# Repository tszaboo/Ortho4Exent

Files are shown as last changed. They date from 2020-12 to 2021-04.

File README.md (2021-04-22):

# Ortho4Exent
Ortholinear keyboard for Exent case

Done in Altium Designer 21.2

Firmware: QMK
The keyboard is found in the QMK repository:\
https://github.com/qmk/qmk_firmware/tree/master/keyboards/tszaboo/ortho4exent

Or build it with the qmk configurator:\
https://config.qmk.fm/#/tszaboo/ortho4exent/LAYOUT

Layout\
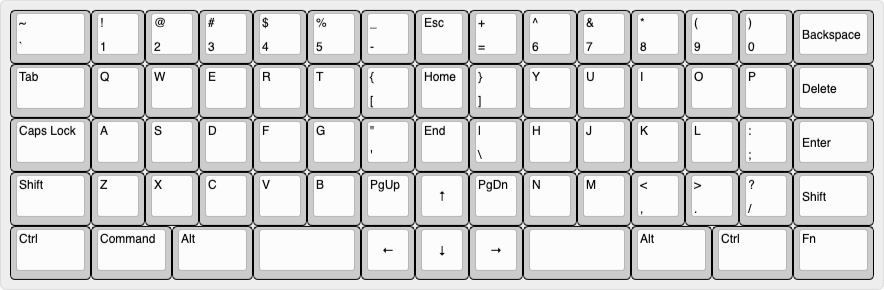
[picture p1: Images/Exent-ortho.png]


PCB\
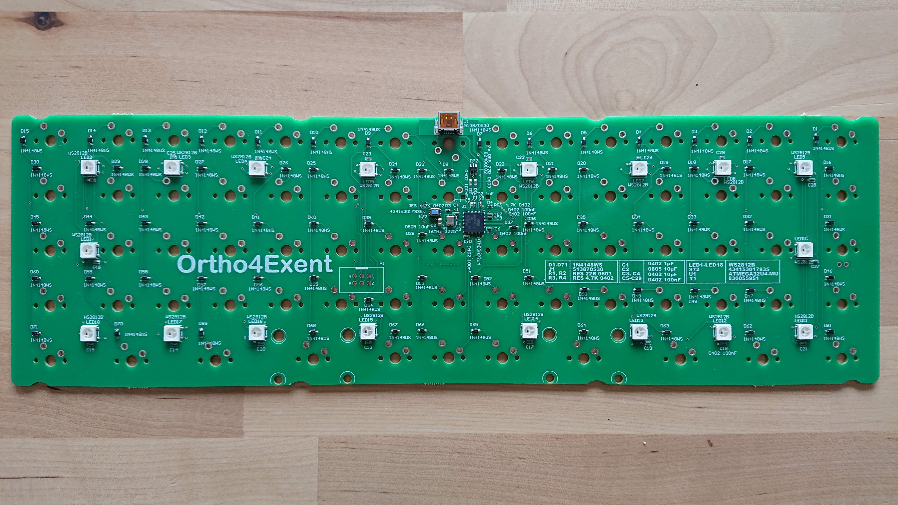
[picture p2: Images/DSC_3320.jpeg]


Assembled board\
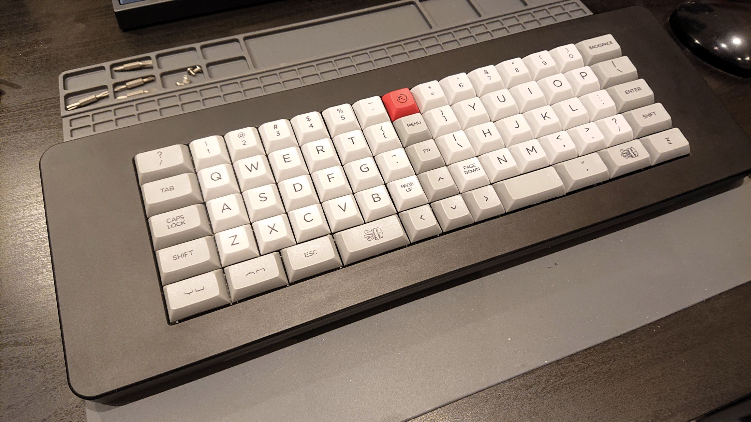
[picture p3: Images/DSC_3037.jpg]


tszaboo \
2021

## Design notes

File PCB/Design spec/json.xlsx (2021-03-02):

{"label":"k00", | x:0, | y:0}, |  | {"label":" | k | 0 | 0 | ","x": | 0 | ,"y": | 0 | ,"w":1.5 | }, | {"label":"k00","x":0,"y":0,"w":1.5},
{"label":"k01", | x:1, | y:0}, |  | {"label":" | k | 0 | 1 | ","x": | 1.5 | ,"y": | 0 |  | }, | {"label":"k01","x":1.5,"y":0},
{"label":"k02", | x:2, | y:0}, |  | {"label":" | k | 0 | 2 | ","x": | 2.5 | ,"y": | 0 |  | }, | {"label":"k02","x":2.5,"y":0},
{"label":"S4", | x:3, | y:0}, |  | {"label":" | k | 0 | 3 | ","x": | 3.5 | ,"y": | 0 |  | }, | {"label":"k03","x":3.5,"y":0},
{"label":"", | x:4, | y:0}, |  | {"label":" | k | 0 | 4 | ","x": | 4.5 | ,"y": | 0 |  | }, | {"label":"k04","x":4.5,"y":0},
{"label":"", | x:5, | y:0}, |  | {"label":" | k | 0 | 5 | ","x": | 5.5 | ,"y": | 0 |  | }, | {"label":"k05","x":5.5,"y":0},
{"label":"", | x:6, | y:0}, |  | {"label":" | k | 0 | 6 | ","x": | 6.5 | ,"y": | 0 |  | }, | {"label":"k06","x":6.5,"y":0},
{"label":"", | x:7, | y:0}, |  | {"label":" | k | 0 | 7 | ","x": | 7.5 | ,"y": | 0 |  | }, | {"label":"k07","x":7.5,"y":0},
{"label":"", | x:8, | y:0}, |  | {"label":" | k | 0 | 8 | ","x": | 8.5 | ,"y": | 0 |  | }, | {"label":"k08","x":8.5,"y":0},
{"label":"", | x:9, | y:0}, |  | {"label":" | k | 0 | 9 | ","x": | 9.5 | ,"y": | 0 |  | }, | {"label":"k09","x":9.5,"y":0},
{"label":"", | x:10, | y:0}, |  | {"label":" | k | 0 | A | ","x": | 10.5 | ,"y": | 0 |  | }, | {"label":"k0A","x":10.5,"y":0},
{"label":"", | x:11, | y:0}, |  | {"label":" | k | 0 | B | ","x": | 11.5 | ,"y": | 0 |  | }, | {"label":"k0B","x":11.5,"y":0},
{"label":"", | x:12, | y:0}, |  | {"label":" | k | 0 | C | ","x": | 12.5 | ,"y": | 0 |  | }, | {"label":"k0C","x":12.5,"y":0},
{"label":"", | x:13, | y:0}, |  | {"label":" | k | 0 | D | ","x": | 13.5 | ,"y": | 0 |  | }, | {"label":"k0D","x":13.5,"y":0},
{"label":"", | x:14, | y:0}, |  | {"label":" | k | 0 | E | ","x": | 14.5 | ,"y": | 0 | ,"w":1.5 | }, | {"label":"k0E","x":14.5,"y":0,"w":1.5},
{"label":"", | x:15, | y:0}, |  | {"label":" | k | 1 | 0 | ","x": | 0 | ,"y": | 1 | ,"w":1.5 | }, | {"label":"k10","x":0,"y":1,"w":1.5},
{"label":"", | x:0, | y:1, | w:1.5}, | {"label":" | k | 1 | 1 | ","x": | 1.5 | ,"y": | 1 |  | }, | {"label":"k11","x":1.5,"y":1},
{"label":"", | x:1.5, | y:1}, |  | {"label":" | k | 1 | 2 | ","x": | 2.5 | ,"y": | 1 |  | }, | {"label":"k12","x":2.5,"y":1},
{"label":"", | x:2.5, | y:1}, |  | {"label":" | k | 1 | 3 | ","x": | 3.5 | ,"y": | 1 |  | }, | {"label":"k13","x":3.5,"y":1},
{"label":"", | x:3.5, | y:1}, |  | {"label":" | k | 1 | 4 | ","x": | 4.5 | ,"y": | 1 |  | }, | {"label":"k14","x":4.5,"y":1},
{"label":"", | x:4.5, | y:1}, |  | {"label":" | k | 1 | 5 | ","x": | 5.5 | ,"y": | 1 |  | }, | {"label":"k15","x":5.5,"y":1},
{"label":"", | x:5.5, | y:1}, |  | {"label":" | k | 1 | 6 | ","x": | 6.5 | ,"y": | 1 |  | }, | {"label":"k16","x":6.5,"y":1},
{"label":"", | x:6.5, | y:1}, |  | {"label":" | k | 1 | 7 | ","x": | 7.5 | ,"y": | 1 |  | }, | {"label":"k17","x":7.5,"y":1},
{"label":"", | x:7.5, | y:1}, |  | {"label":" | k | 1 | 8 | ","x": | 8.5 | ,"y": | 1 |  | }, | {"label":"k18","x":8.5,"y":1},
{"label":"", | x:8.5, | y:1}, |  | {"label":" | k | 1 | 9 | ","x": | 9.5 | ,"y": | 1 |  | }, | {"label":"k19","x":9.5,"y":1},
{"label":"", | x:9.5, | y:1}, |  | {"label":" | k | 1 | A | ","x": | 10.5 | ,"y": | 1 |  | }, | {"label":"k1A","x":10.5,"y":1},
{"label":"", | x:10.5, | y:1}, |  | {"label":" | k | 1 | B | ","x": | 11.5 | ,"y": | 1 |  | }, | {"label":"k1B","x":11.5,"y":1},
{"label":"", | x:11.5, | y:1}, |  | {"label":" | k | 1 | C | ","x": | 12.5 | ,"y": | 1 |  | }, | {"label":"k1C","x":12.5,"y":1},
{"label":"", | x:12.5, | y:1}, |  | {"label":" | k | 1 | D | ","x": | 13.5 | ,"y": | 1 |  | }, | {"label":"k1D","x":13.5,"y":1},
{"label":"", | x:13.5, | y:1, | w:1.5}, | {"label":" | k | 1 | E | ","x": | 14.5 | ,"y": | 1 | ,"w":1.5 | }, | {"label":"k1E","x":14.5,"y":1,"w":1.5},
{"label":"", | x:15, | y:1}, |  | {"label":" | k | 2 | 0 | ","x": | 0 | ,"y": | 2 |  | }, | {"label":"k20","x":0,"y":2},
{"label":"", | x:0, | y:2, | w:1.75}, | {"label":" | k | 2 | 1 | ","x": | 1.5 | ,"y": | 2 |  | }, | {"label":"k21","x":1.5,"y":2},
{"label":"", | x:1.75, | y:2}, |  | {"label":" | k | 2 | 2 | ","x": | 2.5 | ,"y": | 2 |  | }, | {"label":"k22","x":2.5,"y":2},
{"label":"", | x:2.75, | y:2}, |  | {"label":" | k | 2 | 3 | ","x": | 3.5 | ,"y": | 2 |  | }, | {"label":"k23","x":3.5,"y":2},
{"label":"", | x:3.75, | y:2}, |  | {"label":" | k | 2 | 4 | ","x": | 4.5 | ,"y": | 2 |  | }, | {"label":"k24","x":4.5,"y":2},
{"label":"", | x:4.75, | y:2}, |  | {"label":" | k | 2 | 5 | ","x": | 5.5 | ,"y": | 2 |  | }, | {"label":"k25","x":5.5,"y":2},
{"label":"", | x:5.75, | y:2}, |  | {"label":" | k | 2 | 6 | ","x": | 6.5 | ,"y": | 2 |  | }, | {"label":"k26","x":6.5,"y":2},
{"label":"", | x:6.75, | y:2}, |  | {"label":" | k | 2 | 7 | ","x": | 7.5 | ,"y": | 2 |  | }, | {"label":"k27","x":7.5,"y":2},
{"label":"", | x:7.75, | y:2}, |  | {"label":" | k | 2 | 8 | ","x": | 8.5 | ,"y": | 2 |  | }, | {"label":"k28","x":8.5,"y":2},
{"label":"", | x:8.75, | y:2}, |  | {"label":" | k | 2 | 9 | ","x": | 9.5 | ,"y": | 2 |  | }, | {"label":"k29","x":9.5,"y":2},
{"label":"", | x:9.75, | y:2}, |  | {"label":" | k | 2 | A | ","x": | 10.5 | ,"y": | 2 |  | }, | {"label":"k2A","x":10.5,"y":2},
{"label":"", | x:10.75, | y:2}, |  | {"label":" | k | 2 | B | ","x": | 11.5 | ,"y": | 2 |  | }, | {"label":"k2B","x":11.5,"y":2},
{"label":"", | x:11.75, | y:2}, |  | {"label":" | k | 2 | C | ","x": | 12.5 | ,"y": | 2 |  | }, | {"label":"k2C","x":12.5,"y":2},
{"label":"", | x:12.75, | y:2, | w:2.25}, | {"label":" | k | 2 | D | ","x": | 13.5 | ,"y": | 2 |  | }, | {"label":"k2D","x":13.5,"y":2},
{"label":"", | x:15, | y:2}, |  | {"label":" | k | 2 | E | ","x": | 14.5 | ,"y": | 2 |  | }, | {"label":"k2E","x":14.5,"y":2},
{"label":"", | x:0, | y:3, | w:2.25}, | {"label":" | k | 3 | 0 | ","x": | 0 | ,"y": | 3 | ,"w":1.5 | }, | {"label":"k30","x":0,"y":3,"w":1.5},
{"label":"", | x:2.25, | y:3}, |  | {"label":" | k | 3 | 1 | ","x": | 1.5 | ,"y": | 3 |  | }, | {"label":"k31","x":1.5,"y":3},
{"label":"", | x:3.25, | y:3}, |  | {"label":" | k | 3 | 2 | ","x": | 2.5 | ,"y": | 3 |  | }, | {"label":"k32","x":2.5,"y":3},
{"label":"", | x:4.25, | y:3}, |  | {"label":" | k | 3 | 3 | ","x": | 3.5 | ,"y": | 3 |  | }, | {"label":"k33","x":3.5,"y":3},
{"label":"", | x:5.25, | y:3}, |  | {"label":" | k | 3 | 4 | ","x": | 4.5 | ,"y": | 3 |  | }, | {"label":"k34","x":4.5,"y":3},
{"label":"", | x:6.25, | y:3}, |  | {"label":" | k | 3 | 5 | ","x": | 5.5 | ,"y": | 3 |  | }, | {"label":"k35","x":5.5,"y":3},
{"label":"", | x:7.25, | y:3}, |  | {"label":" | k | 3 | 6 | ","x": | 6.5 | ,"y": | 3 |  | }, | {"label":"k36","x":6.5,"y":3},
{"label":"", | x:8.25, | y:3}, |  | {"label":" | k | 3 | 7 | ","x": | 7.5 | ,"y": | 3 |  | }, | {"label":"k37","x":7.5,"y":3},
{"label":"", | x:9.25, | y:3}, |  | {"label":" | k | 3 | 8 | ","x": | 8.5 | ,"y": | 3 |  | }, | {"label":"k38","x":8.5,"y":3},
{"label":"", | x:10.25, | y:3}, |  | {"label":" | k | 3 | 9 | ","x": | 9.5 | ,"y": | 3 |  | }, | {"label":"k39","x":9.5,"y":3},
{"label":"", | x:11.25, | y:3}, |  | {"label":" | k | 3 | A | ","x": | 10.5 | ,"y": | 3 |  | }, | {"label":"k3A","x":10.5,"y":3},
{"label":"", | x:12.25, | y:3, | w:1.75}, | {"label":" | k | 3 | B | ","x": | 11.5 | ,"y": | 3 |  | }, | {"label":"k3B","x":11.5,"y":3},
{"label":"", | x:14, | y:3}, |  | {"label":" | k | 3 | C | ","x": | 12.5 | ,"y": | 3 |  | }, | {"label":"k3C","x":12.5,"y":3},
{"label":"", | x:15, | y:3}, |  | {"label":" | k | 3 | D | ","x": | 13.5 | ,"y": | 3 |  | }, | {"label":"k3D","x":13.5,"y":3},
{"label":"", | x:0, | y:4, | w:1.5}, | {"label":" | k | 3 | E | ","x": | 14.5 | ,"y": | 3 | ,"w":1.5 | }, | {"label":"k3E","x":14.5,"y":3,"w":1.5},
{"label":"", | x:1.5, | y:4}, |  | {"label":" | k | 4 | 0 | ","x": | 0 | ,"y": | 4 | ,"w":1.5 | }, | {"label":"k40","x":0,"y":4,"w":1.5},
{"label":"", | x:2.5, | y:4, | w:1.5}, | {"label":" | k | 4 | 1 | ","x": | 1.5 | ,"y": | 4 | ,"w":1.5 | }, | {"label":"k41","x":1.5,"y":4,"w":1.5},
{"label":"", | x:4, | y:4, | w:7}, | {"label":" | k | 4 | 2 | ","x": | 3 | ,"y": | 4 | ,"w":1.5 | }, | {"label":"k42","x":3,"y":4,"w":1.5},
{"label":"", | x:11, | y:4, | w:1.5}, | {"label":" | k | 4 | 3 | ","x": | 4.5 | ,"y": | 4 | ,"w":2 | }, | {"label":"k43","x":4.5,"y":4,"w":2},
{"label":"", | x:13, | y:4}, |  | {"label":" | k | 4 | 4 | ","x": | 6.5 | ,"y": | 4 |  | }, | {"label":"k44","x":6.5,"y":4},
{"label":"", | x:14, | y:4}, |  | {"label":" | k | 4 | 5 | ","x": | 7.5 | ,"y": | 4 |  | }, | {"label":"k45","x":7.5,"y":4},
{"label":"", | x:15, | y:4} |  | {"label":" | k | 4 | 6 | ","x": | 8.5 | ,"y": | 4 |  | }, | {"label":"k46","x":8.5,"y":4},
 |  |  |  | {"label":" | k | 4 | 7 | ","x": | 9.5 | ,"y": | 4 | ,"w":2 | }, | {"label":"k47","x":9.5,"y":4,"w":2},
 |  |  |  | {"label":" | k | 4 | 8 | ","x": | 11.5 | ,"y": | 4 | ,"w":1.5 | }, | {"label":"k48","x":11.5,"y":4,"w":1.5},
 |  |  |  | {"label":" | k | 4 | 9 | ","x": | 13 | ,"y": | 4 | ,"w":1.5 | }, | {"label":"k49","x":13,"y":4,"w":1.5},
 |  |  |  | {"label":" | k | 4 | A | ","x": | 14.5 | ,"y": | 4 | ,"w":1.5 | }, | {"label":"k4A","x":14.5,"y":4,"w":1.5},

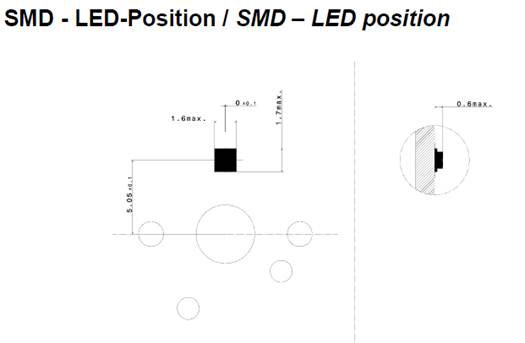
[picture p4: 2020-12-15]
PCB/Design spec/uCZFxpV.jpg

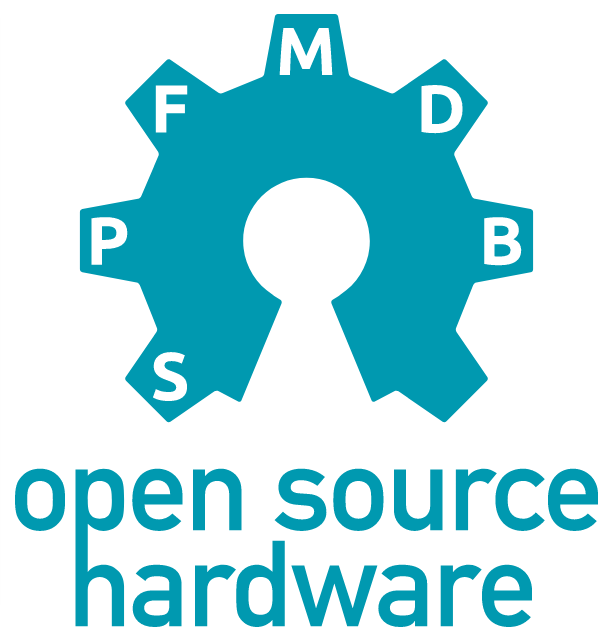
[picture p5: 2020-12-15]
PCB/Design spec/OSHW.PNG

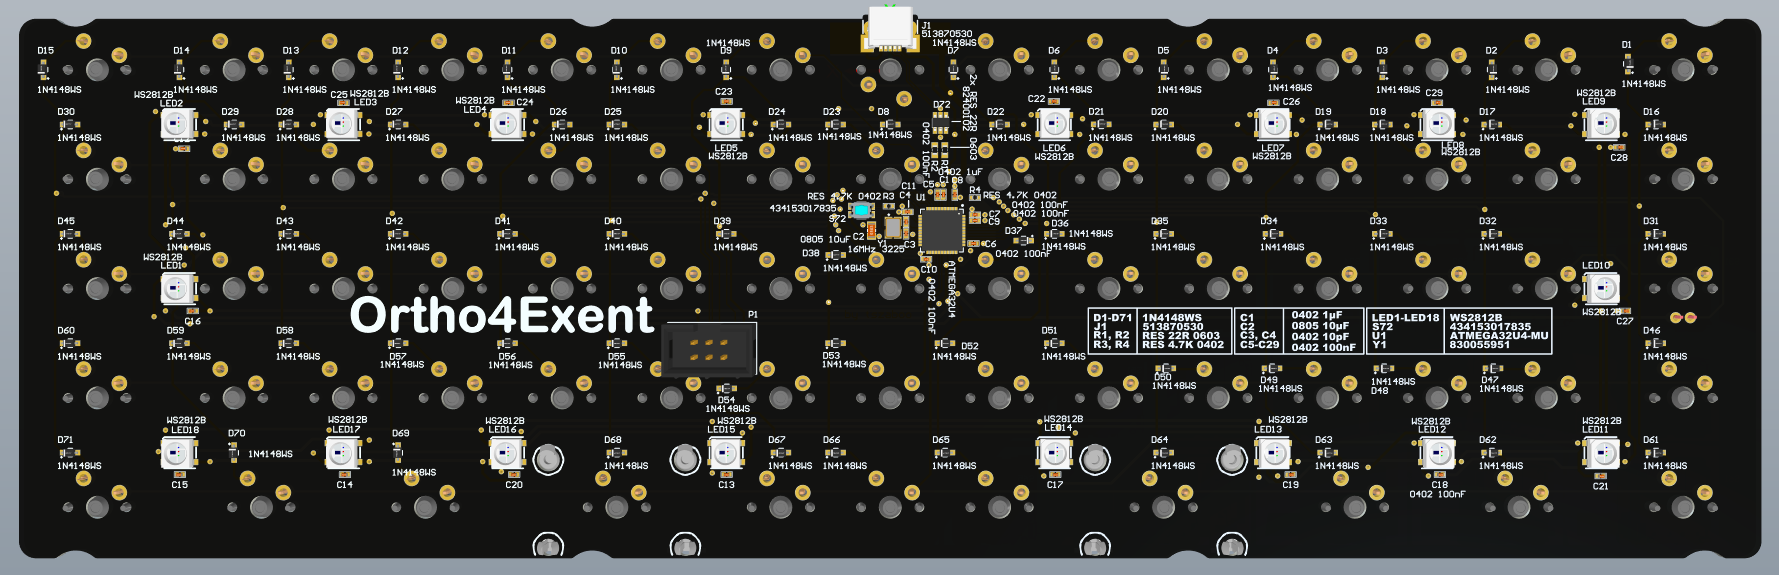
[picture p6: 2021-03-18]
Images/PCB Altium.PNG

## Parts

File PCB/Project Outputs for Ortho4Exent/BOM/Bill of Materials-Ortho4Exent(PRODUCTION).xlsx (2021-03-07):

Designator | Quantity | DESCIPTION | Footprint | MANUF | MANUFCODE
C1 | 1 | CAP SMD 0402 1 µF 10V X5R | CAPC0402N | WE | 885012105012
C2 | 1 | CAP SMD 0805 10 µF 10 V X5R | CAPC0805N | WE | 885012107010
C3, C4 | 2 | CAP SMD 0402 10 pF 10V NP0 | CAPC0402N | WE | 885012005007
C5, C6, C7, C8, C9, C10, C11, C12, C13, C14, C15, C16, C17, C18, C19, C20, C21, C22, C23, C24, C25, C26, C27, C28, C29 | 25 | CAP SMD 0402 100 nF 10V X5R | CAPC0402N | WE | 885012105010
D1, D2, D3, D4, D5, D6, D7, D8, D9, D10, D11, D12, D13, D14, D15, D16, D17, D18, D19, D20, D21, D22, D23, D24, D25, D26, D27, D28, D29, D30, D31, D32, D33, D34, D35, D36, D37, D38, D39, D40, D41, D42, D43, D44, D45, D46, D47, D48, D49, D50, D51, D52, D53, D54, D55, D56, D57, D58, D59, D60, D61, D62, D63, D64, D65, D66, D67, D68, D69, D70, D71 | 71 | DIODE GEN PURP 80V 125MA SOD323 | SOD323FL | ON Semi | 1N4148WS
D72 | 1 | WE-TVS TVS Diode, High Speed Series, SOT23-6L, VDC = 5V | SOT23-6L | WE | 82400102
J1 | 1 | USB - mini B USB 2.0 OTG Receptacle Connector 5 Position Surface Mount | 513870530 | MOLEX | 513870530
LED1, LED2, LED3, LED4, LED5, LED6, LED7, LED8, LED9, LED10, LED11, LED12, LED13, LED14, LED15, LED16, LED17, LED18 | 18 | ADDRESS LED RED/GRN/BLUE | WS2812 | Worldsemi | WS2812B
R1, R2 | 2 | RES SMD 22 OHM 1% 1/10W 100PPM 0603 | RESC0603N | VISHAY | CRCW060322R0FKEA
R3, R4 | 2 | RES SMD 4.7K OHM 1% 1/16W 100PPM 0402 | RESC0402N | VISHAY | CRCW04024K70FKED
S72 | 1 | SWITCH TACTILE SPST-NO 0.05A 12V | 434153017835 | WE | 434153017835
U1 | 1 | IC MCU 8BIT 32KB FLASH 44VQFN | 44PW_M | Microchip | ATMEGA32U4-MU-ND
Y1 | 1 | CRYSTAL 16.0000MHZ 18PF SMD | WE-XTAL_CFPX-180 | WE/IQD | 830055951

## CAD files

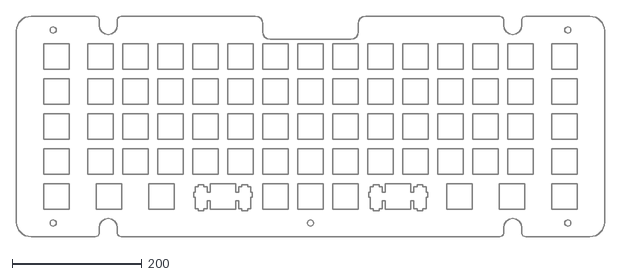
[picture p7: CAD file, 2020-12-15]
PCB/Design spec/ortho_plate.dxf
906.9 x 340.1

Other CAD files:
PCB/Design spec/PCB_layout.dwg
PCB/Plate/AutoCAD PCB/pcb.DWG
PCB/Design spec/65-PLATE-01_dimension.dwg

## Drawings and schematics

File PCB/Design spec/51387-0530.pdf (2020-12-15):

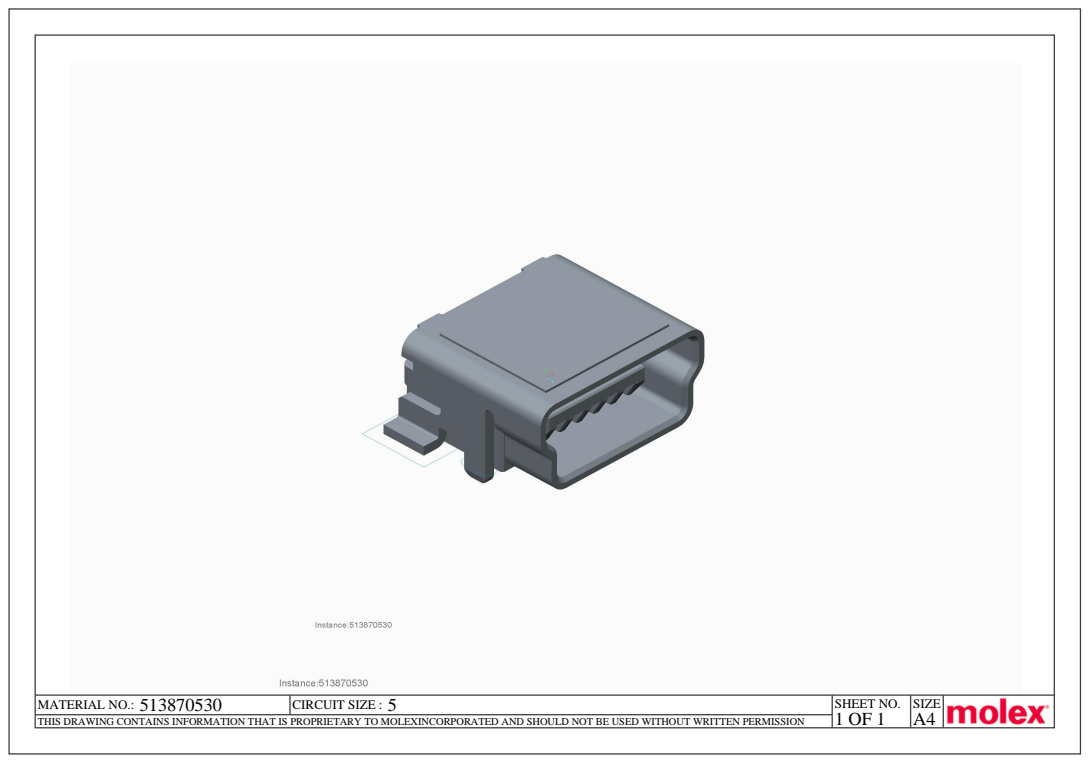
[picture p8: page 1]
MATERIAL NO.: 513870530; CIRCUIT SIZE : 5; SHEET NO.; SIZE

THIS DRAWING CONTAINS INFORMATION THAT IS PROPRIETARY TO MOLEXINCORPORATED AND SHOULD NOT BE USED WITHOUT WRITTEN PERMISSION

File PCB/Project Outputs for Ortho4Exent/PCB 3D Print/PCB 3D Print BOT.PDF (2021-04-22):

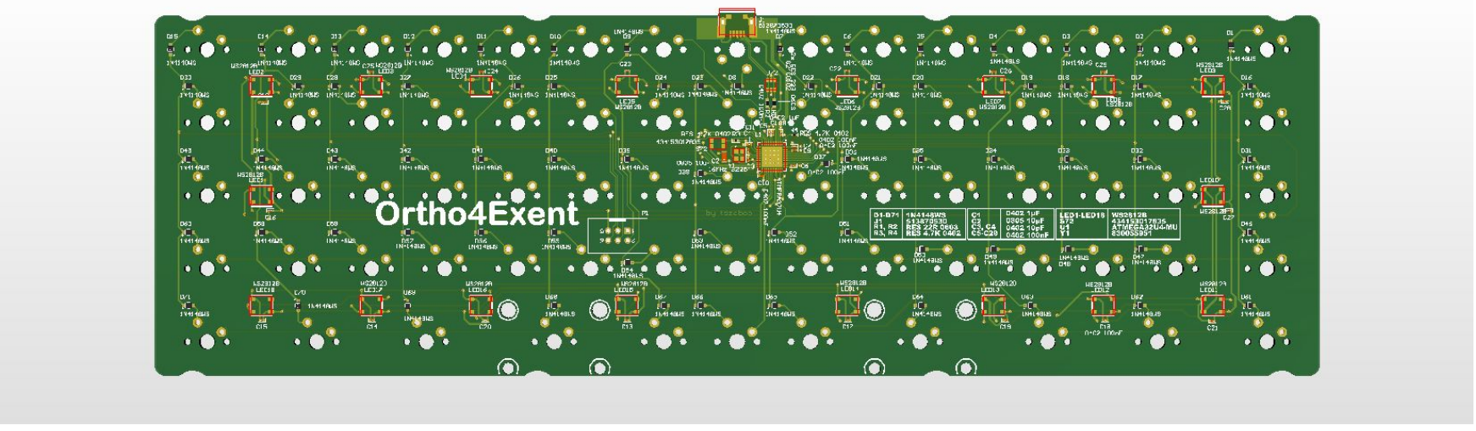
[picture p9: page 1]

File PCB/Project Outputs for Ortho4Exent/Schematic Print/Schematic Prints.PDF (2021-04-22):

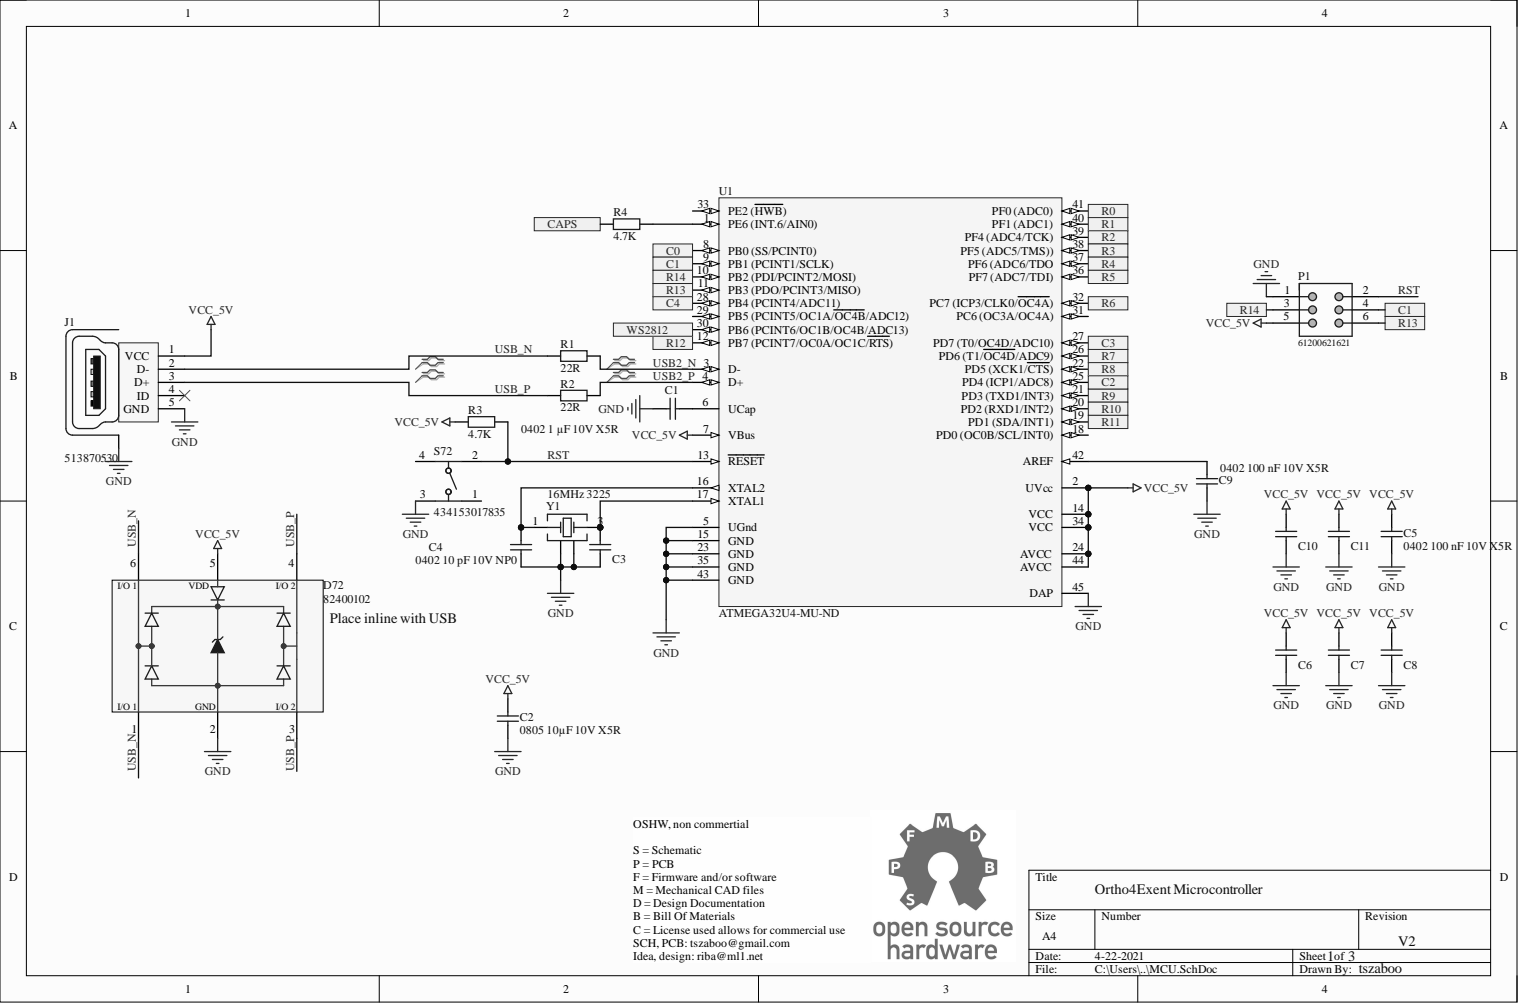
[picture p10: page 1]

C1 | | | R4
R1 4 | | | R5

1 6MHz 3 2 2 5 | 1 7 | 1 4

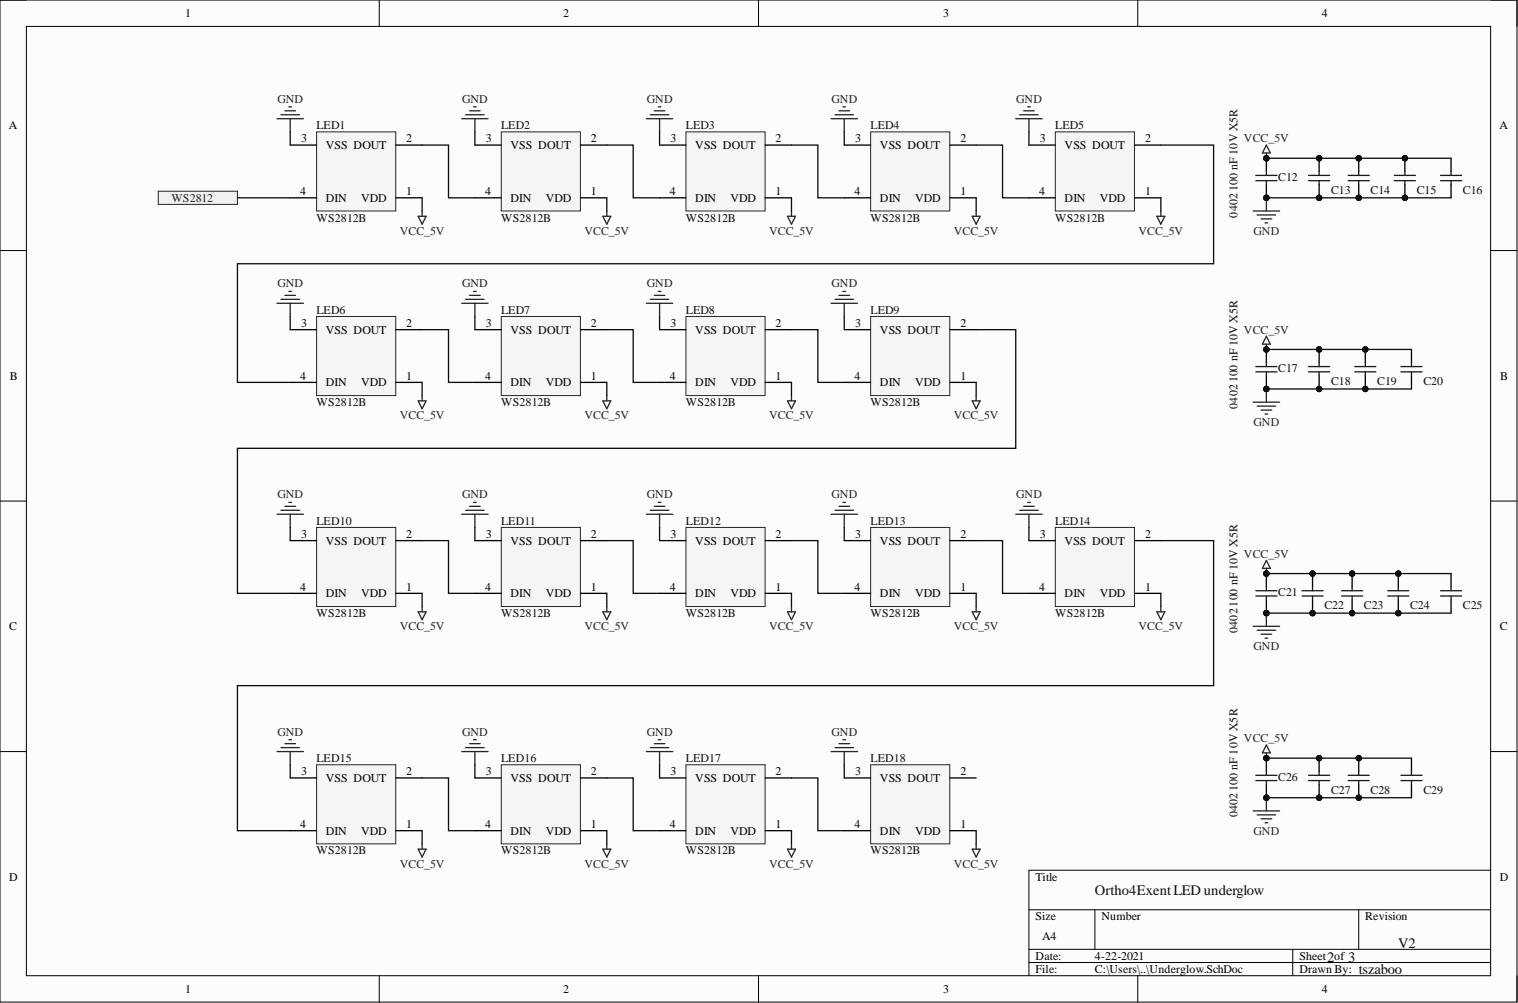
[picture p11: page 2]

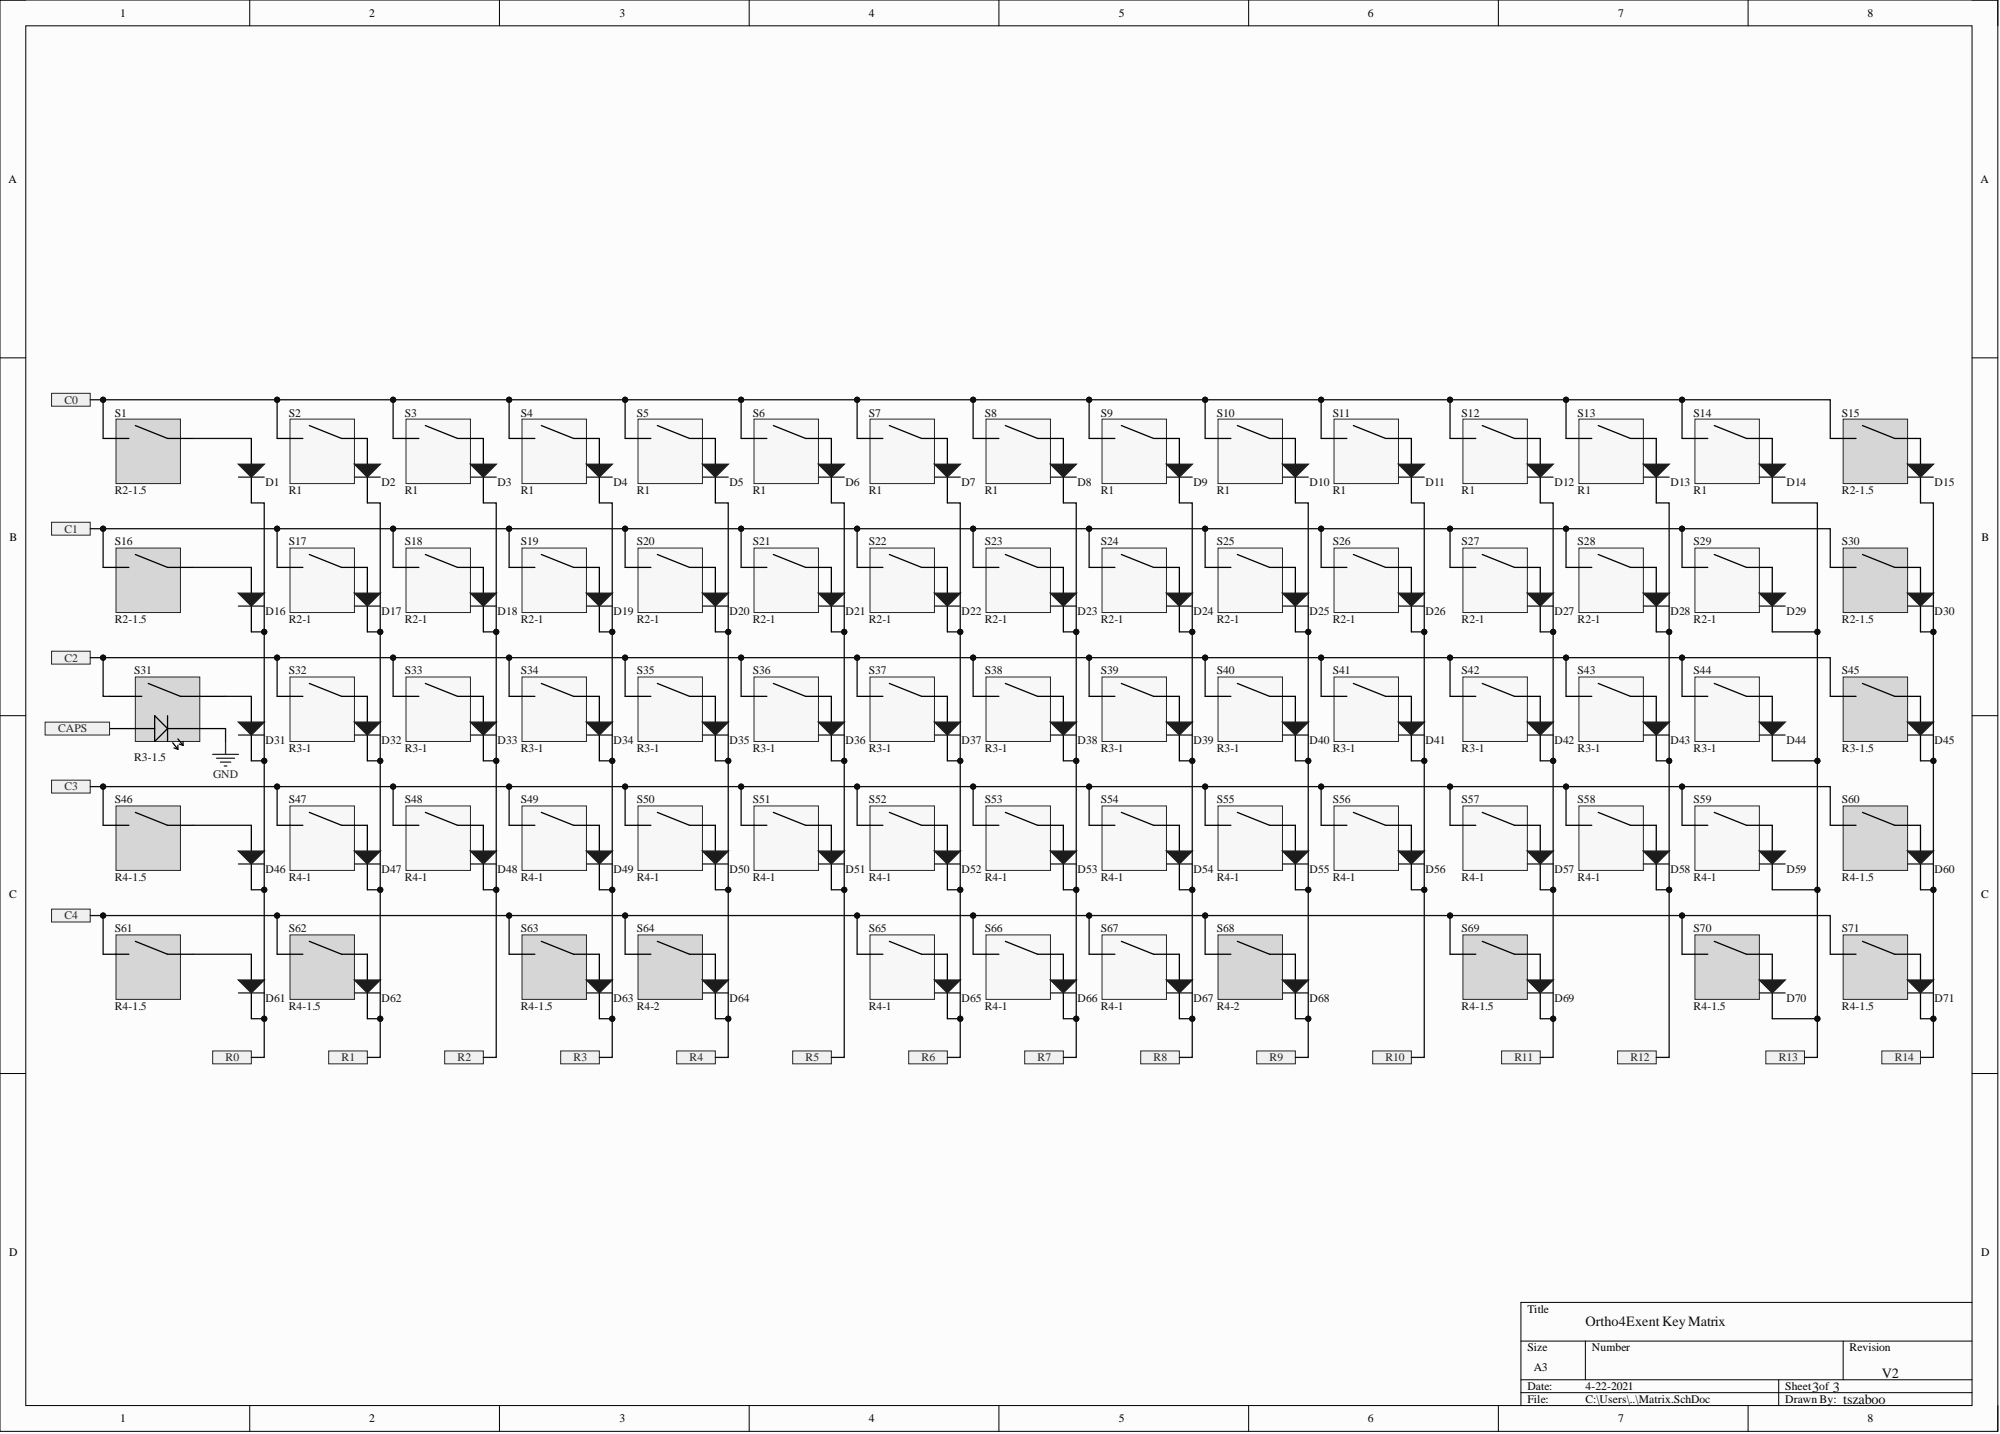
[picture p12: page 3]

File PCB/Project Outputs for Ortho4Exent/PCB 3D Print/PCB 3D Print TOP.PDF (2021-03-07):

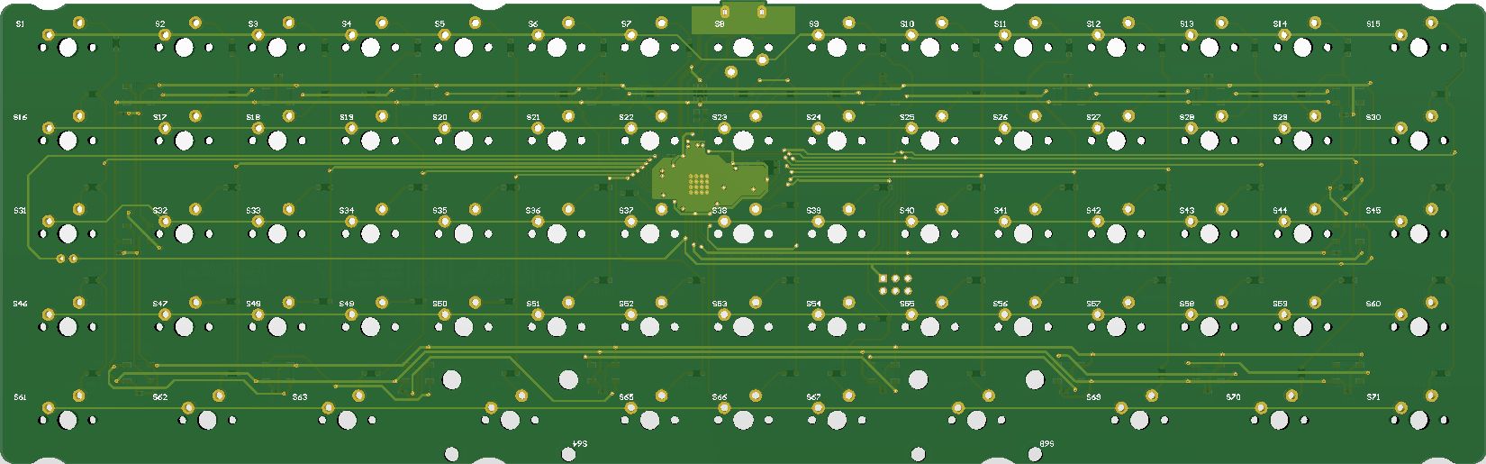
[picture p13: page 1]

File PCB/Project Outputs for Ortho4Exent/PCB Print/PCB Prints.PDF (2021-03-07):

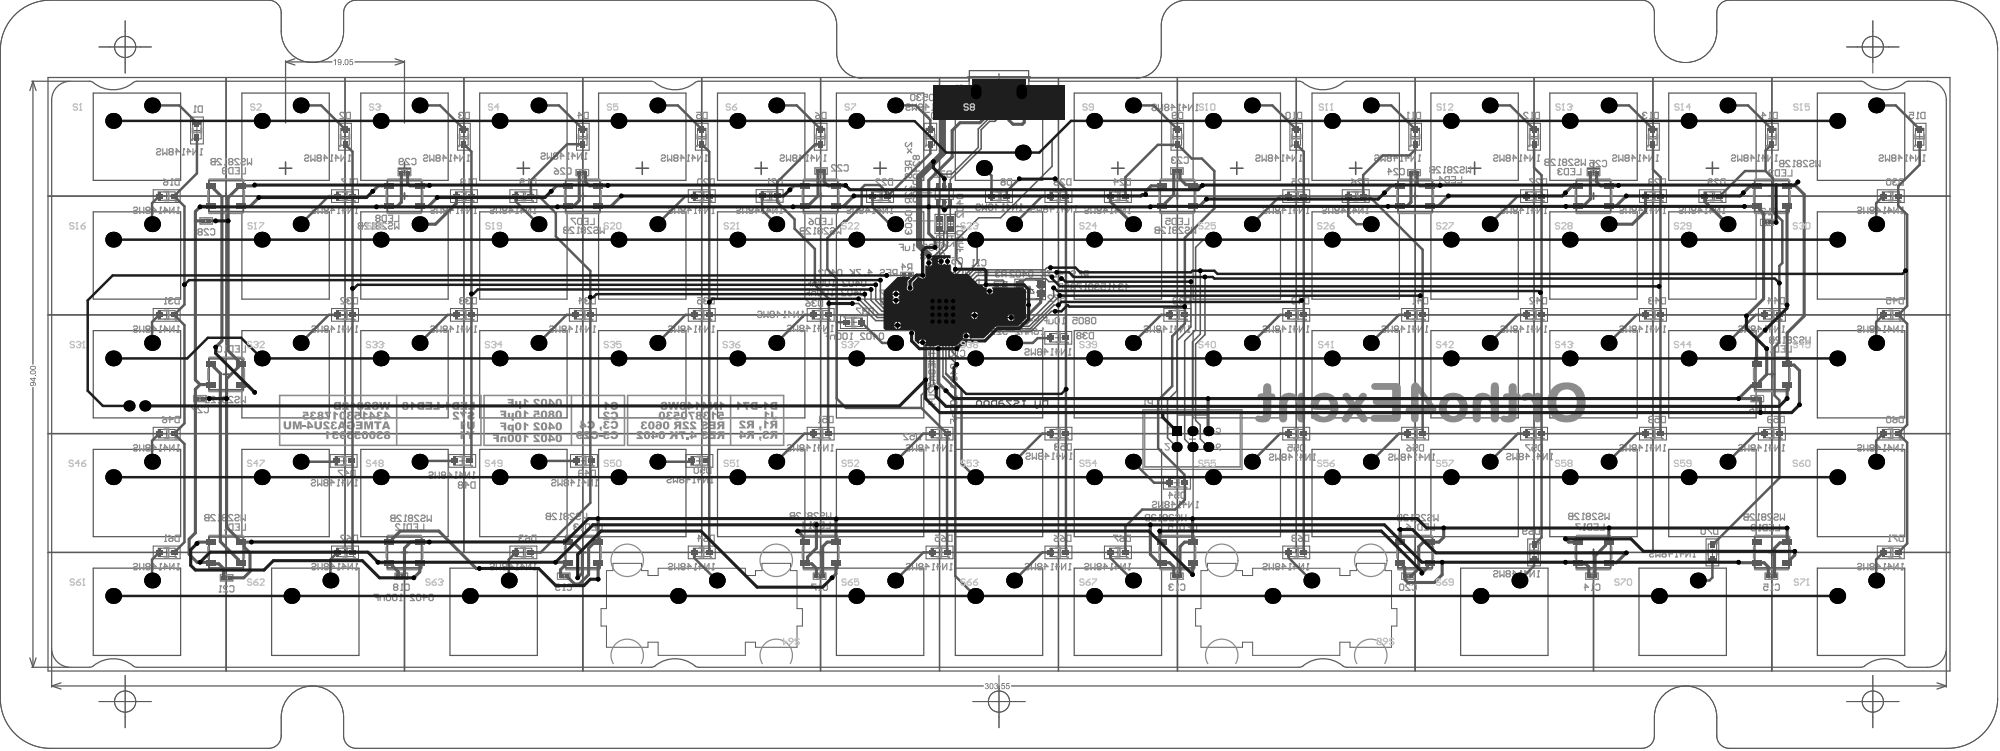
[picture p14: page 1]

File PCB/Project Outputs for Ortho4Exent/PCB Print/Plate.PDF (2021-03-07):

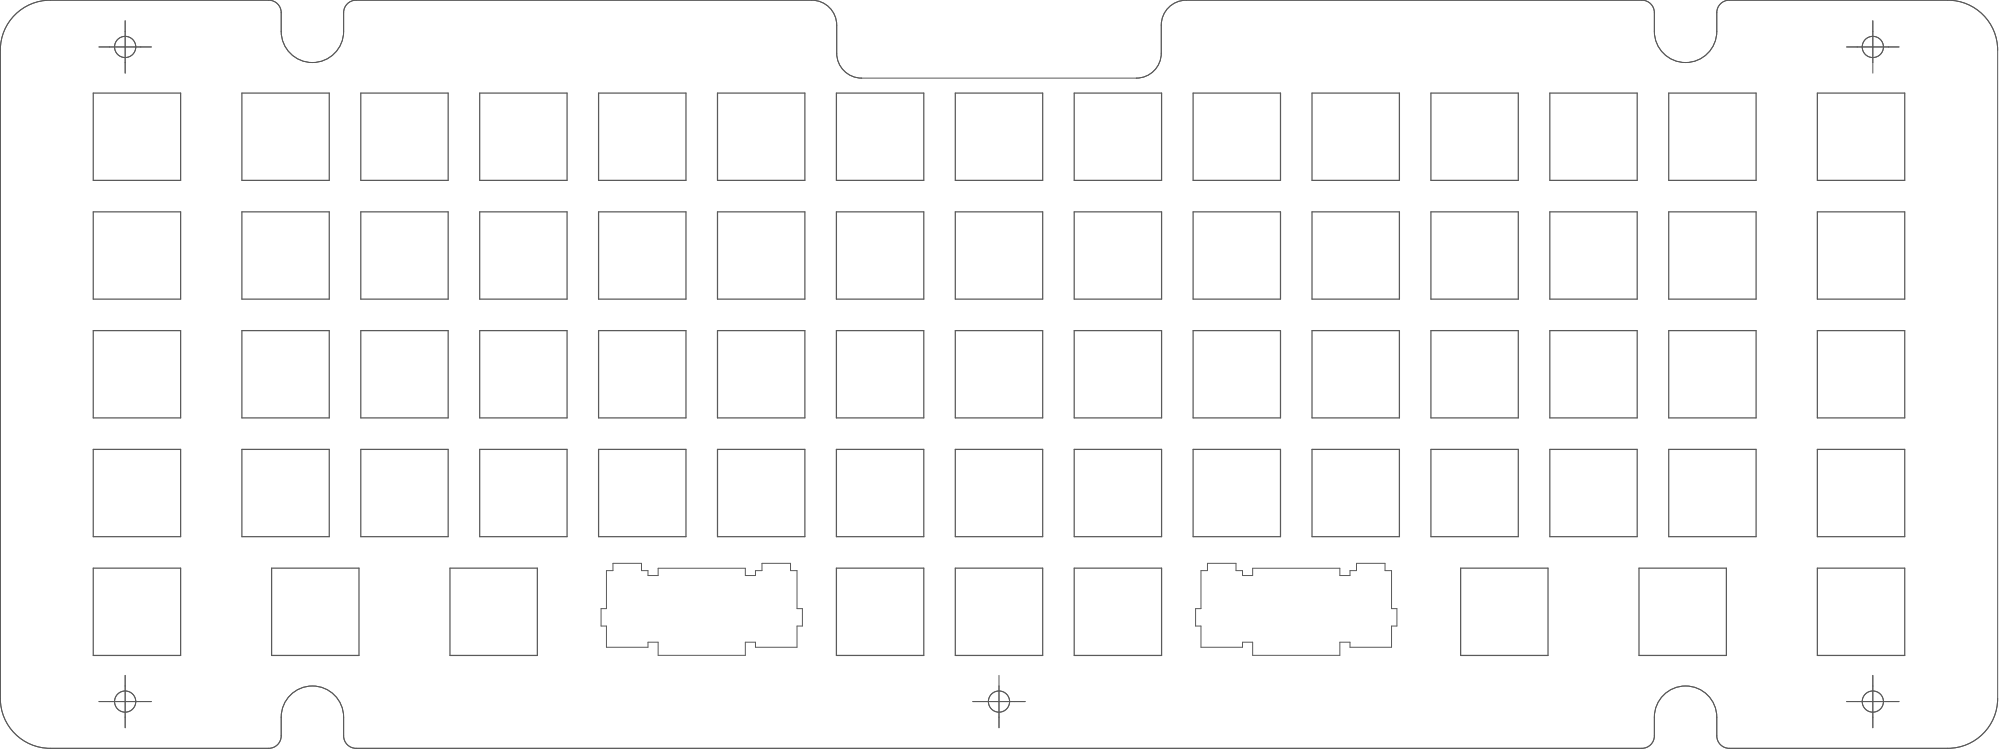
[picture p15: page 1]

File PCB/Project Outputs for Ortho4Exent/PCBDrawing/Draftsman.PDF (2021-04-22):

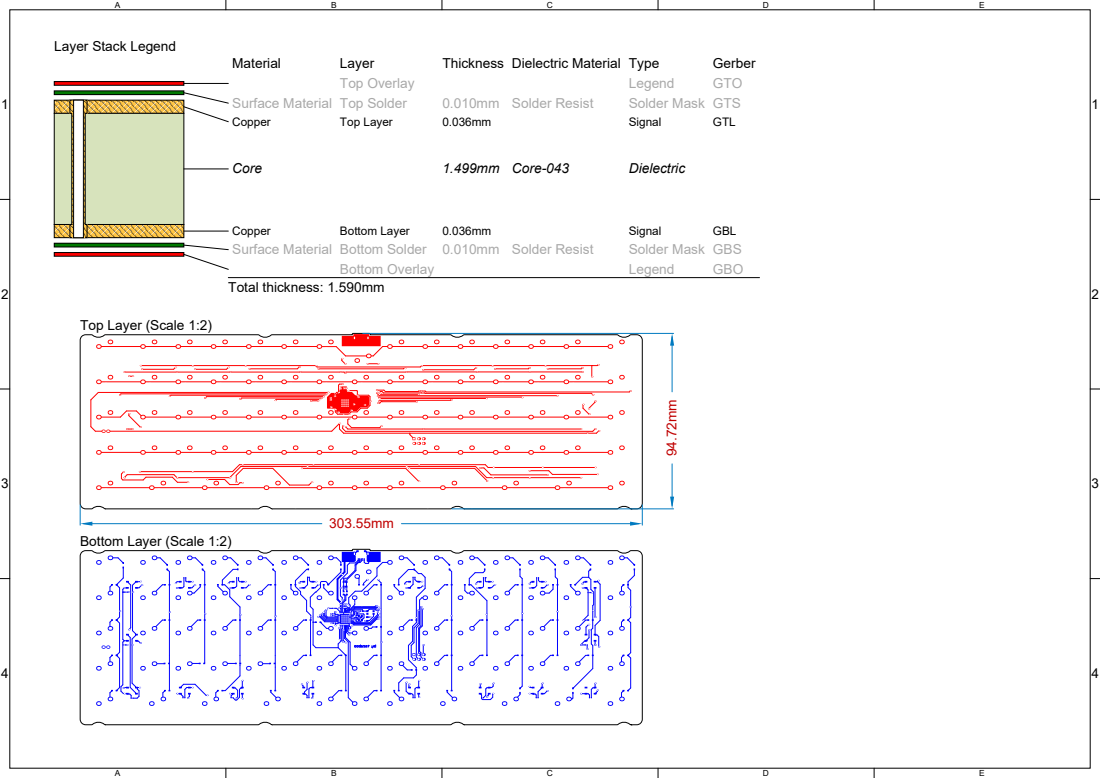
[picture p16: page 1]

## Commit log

2020-12-15 Adding design spec files, generating PDF WIP outputs
    [65-PLATE-01_dimension.dwg, MCU.SchDoc, Matrix.SchDoc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]
2020-12-17 routing WIP update
    [MCU.SchDoc, Ortho4Exent.PrjPcb, Underglow.SchDoc]
2020-12-17 PCB routing complete
    [MCU.SchDoc, Ortho4Exent.PrjPcb]
2020-12-18 Schematic and pcb layout relase in PDF
    [Bill of Materials-Ortho4Exent(PRODUCTION).xlsx, Bill of Materials-Ortho4Exent.xlsx, MCU.SchDoc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]
2020-12-26 silkscreen + programming connector
    [Bill of Materials-Ortho4Exent(PRODUCTION).xlsx, MCU.SchDoc, Production BOM-Ortho4Exent(PRODUCTION).xlsx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]
2020-12-27 Adding TVS diode
    [Bill of Materials-Ortho4Exent(PRODUCTION).xlsx, Bill of Materials-Ortho4Exent.xlsx, MCU.SchDoc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]
2021-03-02 V1 . do not order, see change list
    Change list for version 2:
    1. USB pinout
    2. WS2812 silkscreen
    3. BOM on silkscreen
    4. Diode order code
    [Bill of Materials-Ortho4Exent(PRODUCTION).xlsx, MCU.SchDoc, Ortho4Exent.PrjPcb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]
2021-03-02 V2 for review
    [Bill of Materials-Ortho4Exent(PRODUCTION).xlsx, MCU.SchDoc, Matrix.SchDoc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]
2021-03-07 release V2
    [Bill of Materials-Ortho4Exent(PRODUCTION).xlsx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]
2021-03-15 Adding DXF export for plate
    [pcb.DWG]
2021-03-15 Altium project update
    [Ortho4Exent.PrjPcb]
2021-04-22 SCH cleanup, generating PDFs again
    [MCU.SchDoc, Matrix.SchDoc, Underglow.SchDoc]
